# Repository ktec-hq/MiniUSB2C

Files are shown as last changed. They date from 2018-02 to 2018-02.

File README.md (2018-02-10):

MiniUSB2C
Idea from https://github.com/manisteinn/usb-type-c-hhkb
MiniUSB2C is for some other keyboards that use MiniUSB like below.
先拆掉之前的MiniUSB，有热风枪比较好拆。
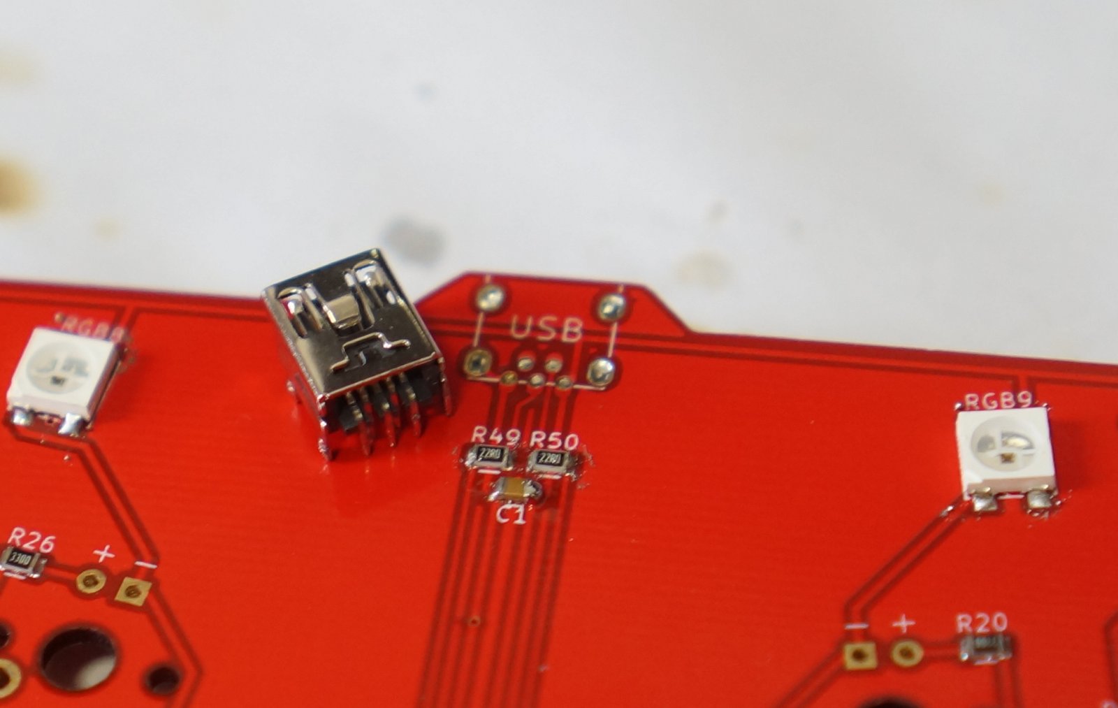
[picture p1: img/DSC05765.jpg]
 

拆下后孔可以不用清理，找一些针焊上去。miniusb的5个脚的孔需要使用细一些的，我用的是二极管上剪的。下图这一面可以先焊上。
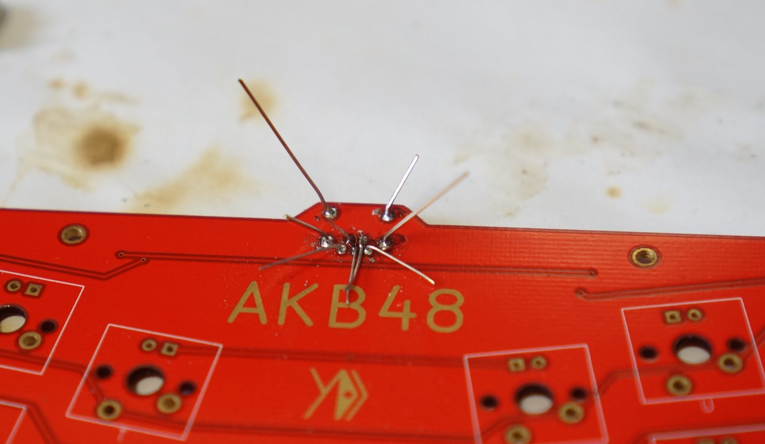
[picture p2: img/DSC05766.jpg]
 

这一面的，先剪短了再焊上。
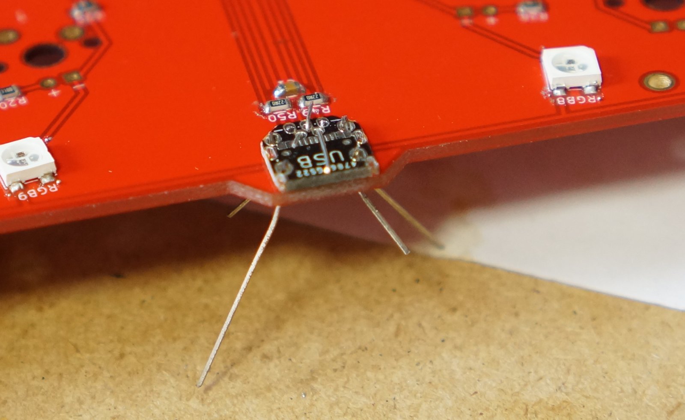
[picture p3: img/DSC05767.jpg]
 
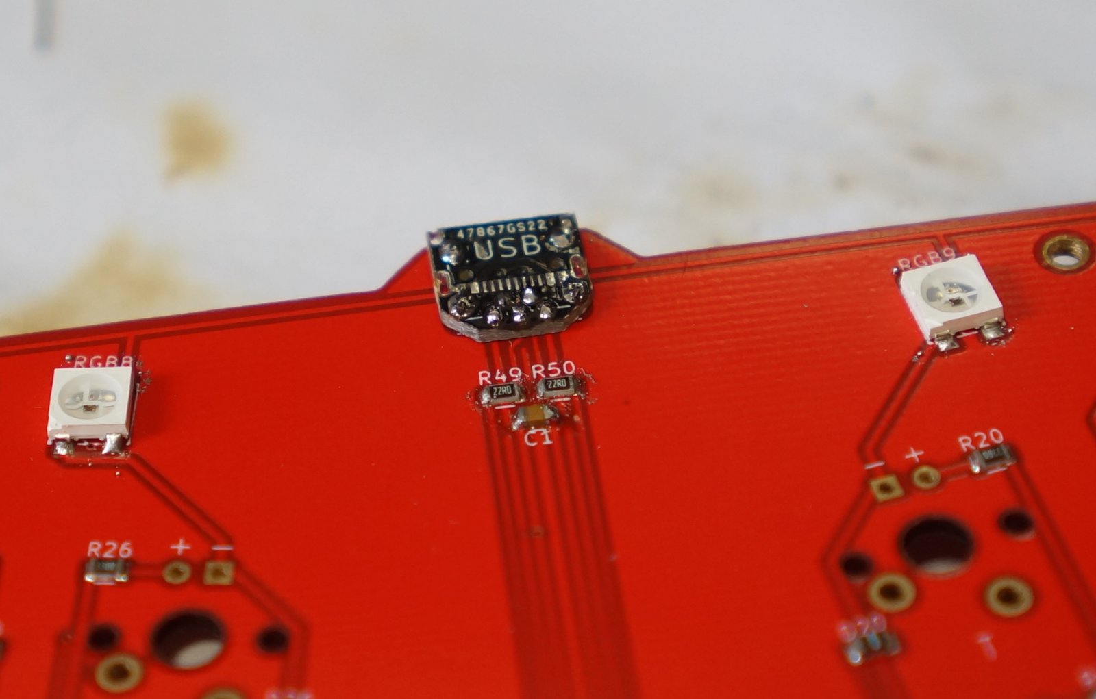
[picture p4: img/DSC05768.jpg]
 

给USB Type-C的焊盘上锡（锡膏更好用），然后用风枪吹好，不要有粘连，要是有连上就用镊子给它划开一下，把多余的锡划走。
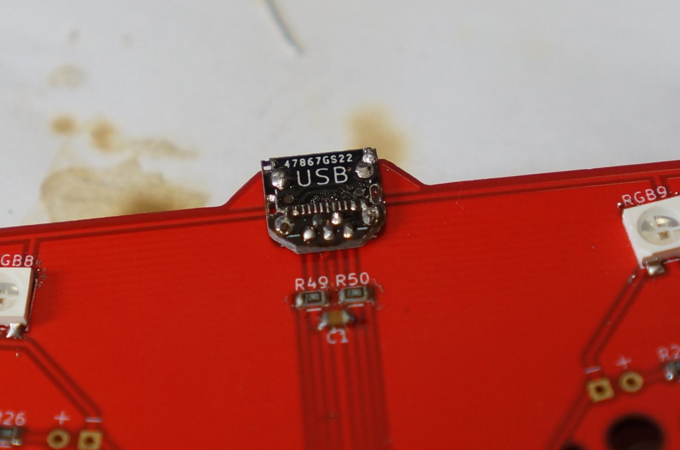
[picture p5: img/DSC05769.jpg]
 

然后把Type-C的母座焊上，这里使用的是16p的母座。上机前务必用万用表测试一下键盘的VCC和GND没有短路，如果有短跳检查一下哪里没焊好，重新焊。
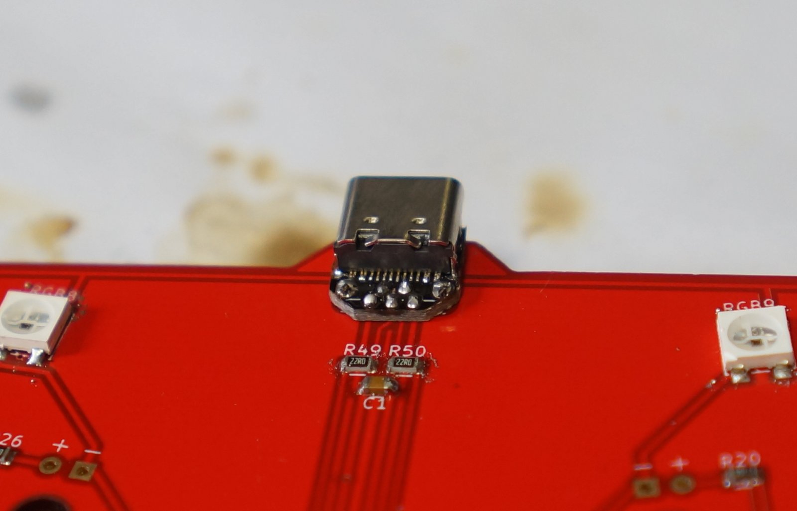
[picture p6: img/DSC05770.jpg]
 

工作完美。
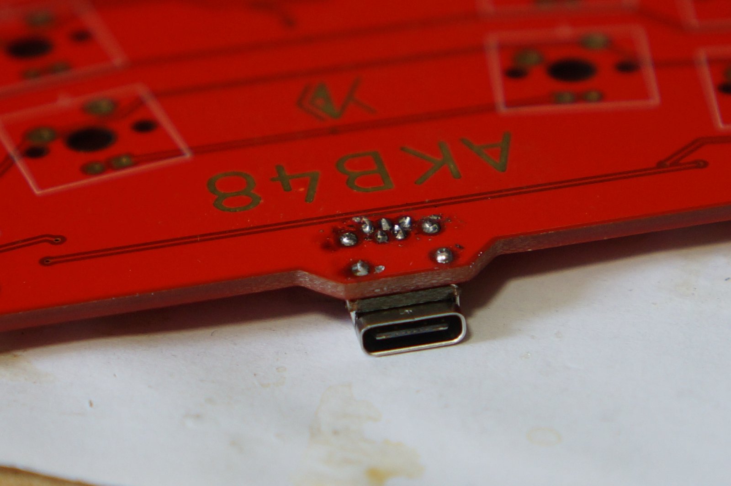
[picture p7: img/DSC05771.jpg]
 

下面这个是本身已经焊好轴的PCB(YDPM40 demo green)，更换Type-C接口
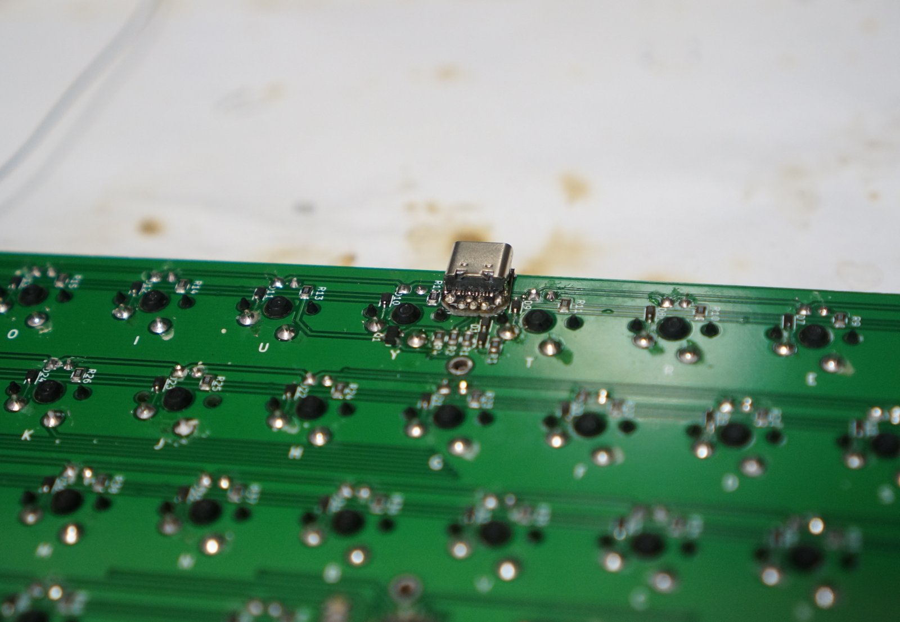
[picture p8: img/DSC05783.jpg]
 
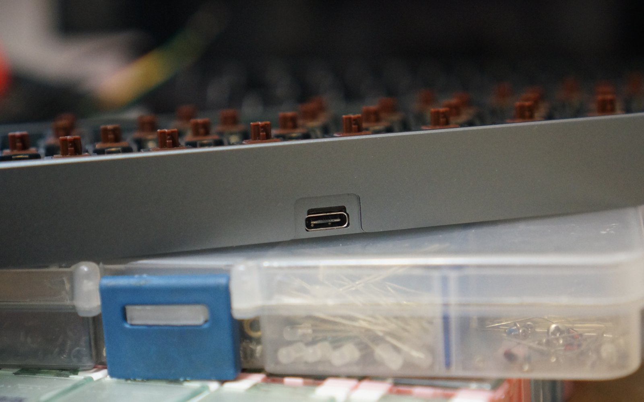
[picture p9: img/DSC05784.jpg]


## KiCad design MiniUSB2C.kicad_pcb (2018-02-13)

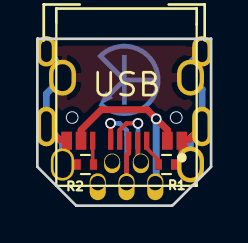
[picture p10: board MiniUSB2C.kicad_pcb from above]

Board: 2 copper layers, 9.7 x 9.3 mm, 5 parts (1 on the bottom side), 6 nets.

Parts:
J1: USB; DX_USB
LOGO4: KTEC_LOGO; KTEC_Logo
R1, R2: 5k1; R_0402
USB1: USB_TYPE-C_16PIN; USB_TYPE-C_16PIN2

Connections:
/USB_D+: J1.3, USB1.6, USB1.8
/USB_D-: J1.2, USB1.5, USB1.7
GNDPWR: J1.5, J1.P$6, J1.P$7, J1.P$8, J1.P$9, R1.2, R2.2, USB1.0, USB1.1, USB1.12
unnamed: R1.1, USB1.4
unnamed: R2.1, USB1.10
VBUS: J1.1, USB1.2, USB1.11

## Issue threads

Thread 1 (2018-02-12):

doesn't work with C to C.

yangdigi, 2018-02-12:
Need to add 5.1K resistor  between CC1 an d GND.  I will test it later.

yangdigi, 2018-02-12:
yes. 5.1k pull down is necessary for cc1 and cc2.

winterNebs, 2020-11-30:
Hi, Sorry to bother you on such an old project, for the 2 5.1k pull down resistors, is there any way to add them with this board? Or would that require modification. Thanks!

Closed 2018-02-12.

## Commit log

2018-01-01 first ver
    [MiniUSB2C.kicad_pcb, MiniUSB2C.sch]
2018-02-03 smaller smaller
    [MiniUSB2C.kicad_pcb]
2018-02-10 img and gerber
    [MiniUSB2C-B.Cu.gbr, MiniUSB2C-B.Mask.gbr, MiniUSB2C-B.SilkS.gbr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]
2018-02-13 v3: add 5.1K for CC pin
    [MiniUSB2C.kicad_pcb, MiniUSB2C.sch]
